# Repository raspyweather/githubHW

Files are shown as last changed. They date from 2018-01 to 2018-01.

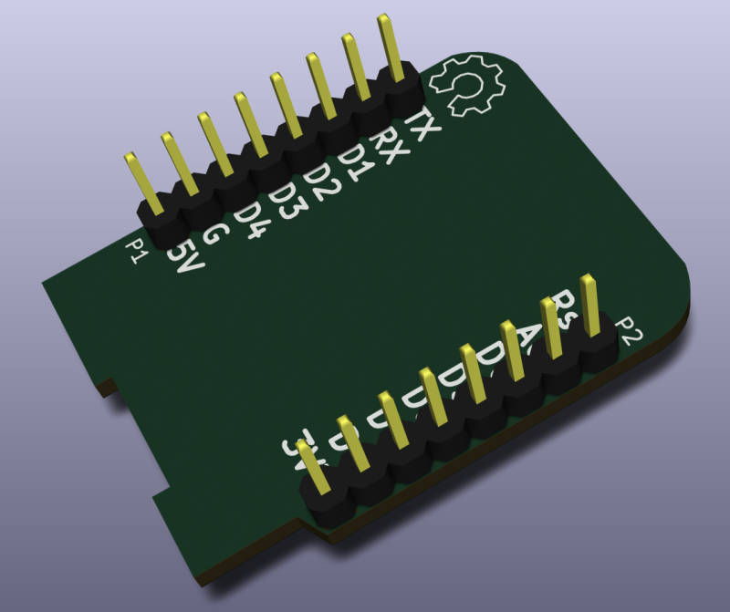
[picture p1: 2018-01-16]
d1_mini_kicad-master/template/meta/brd.png

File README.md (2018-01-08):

#  Github Calendar in Hardware
This is a very basic try to bring github's calendar to hardware. Who wouldn't like to get up and look at the glorious contribution history of the path?

just an image from githubs documentation

(not my calendar btw ☺)

# introduction
Since I'm a student, manufacturing cost need to be low, why I decided to use three 10cm x 10cm pcbs and solder all components by hand. Because it is cheaper using one mutli-purpose board than two specific pcb designs, I decided to do so, not assemblying unnecessary components on these boards. 

## first/main pcb
All parts assembled 
- WeMos D1 mini (KiCad files used from https://github.com/jerome-labidurie/d1_mini_kicad)
- 2x [TPIC6B595N](http://www.ti.com/lit/ds/symlink/tpic6b595.pdf)
- [TLC5940](http://www.ti.com/lit/ds/symlink/tlc5940.pdf)
- *some* leds
- 4x Buttons
- 1x Poti

pcb layout

## following two pcbs
- TLC5940
- *some* leds

## Total Circuit (connected ones)
only TLC5940 and leds assembled.
total scheme

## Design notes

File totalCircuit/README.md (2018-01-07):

# Total Circuit Scheme
This folder contains the schematic of all three pcbs needed for the total circuit.

It is only existing for documentary purposes.

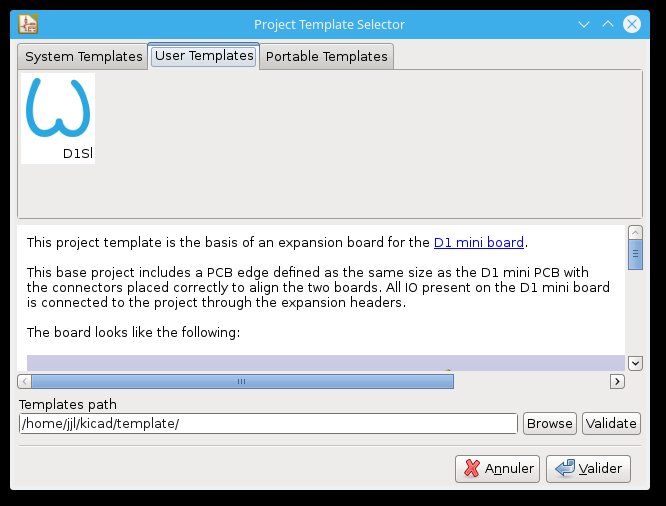
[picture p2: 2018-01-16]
d1_mini_kicad-master/work/img/screenshot1.jpg

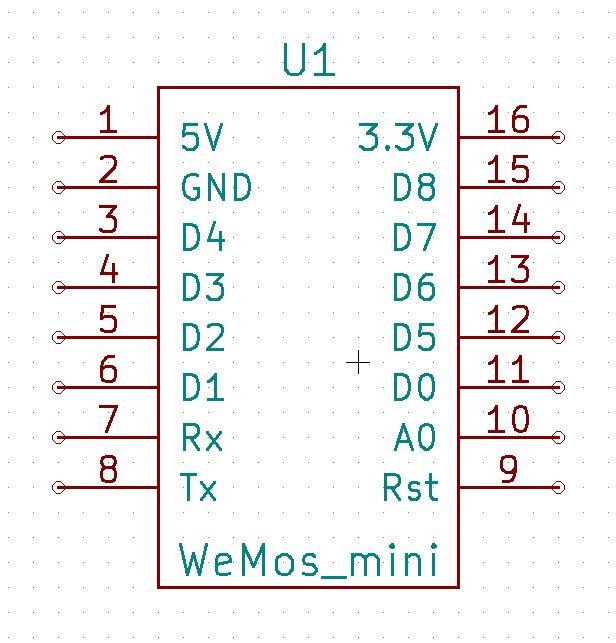
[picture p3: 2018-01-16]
d1_mini_kicad-master/work/img/screenshot2.jpg

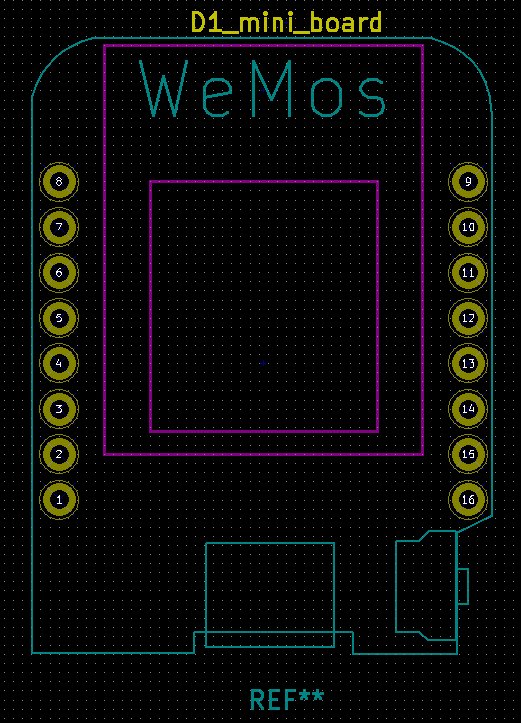
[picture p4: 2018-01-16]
d1_mini_kicad-master/work/img/screenshot3.jpg

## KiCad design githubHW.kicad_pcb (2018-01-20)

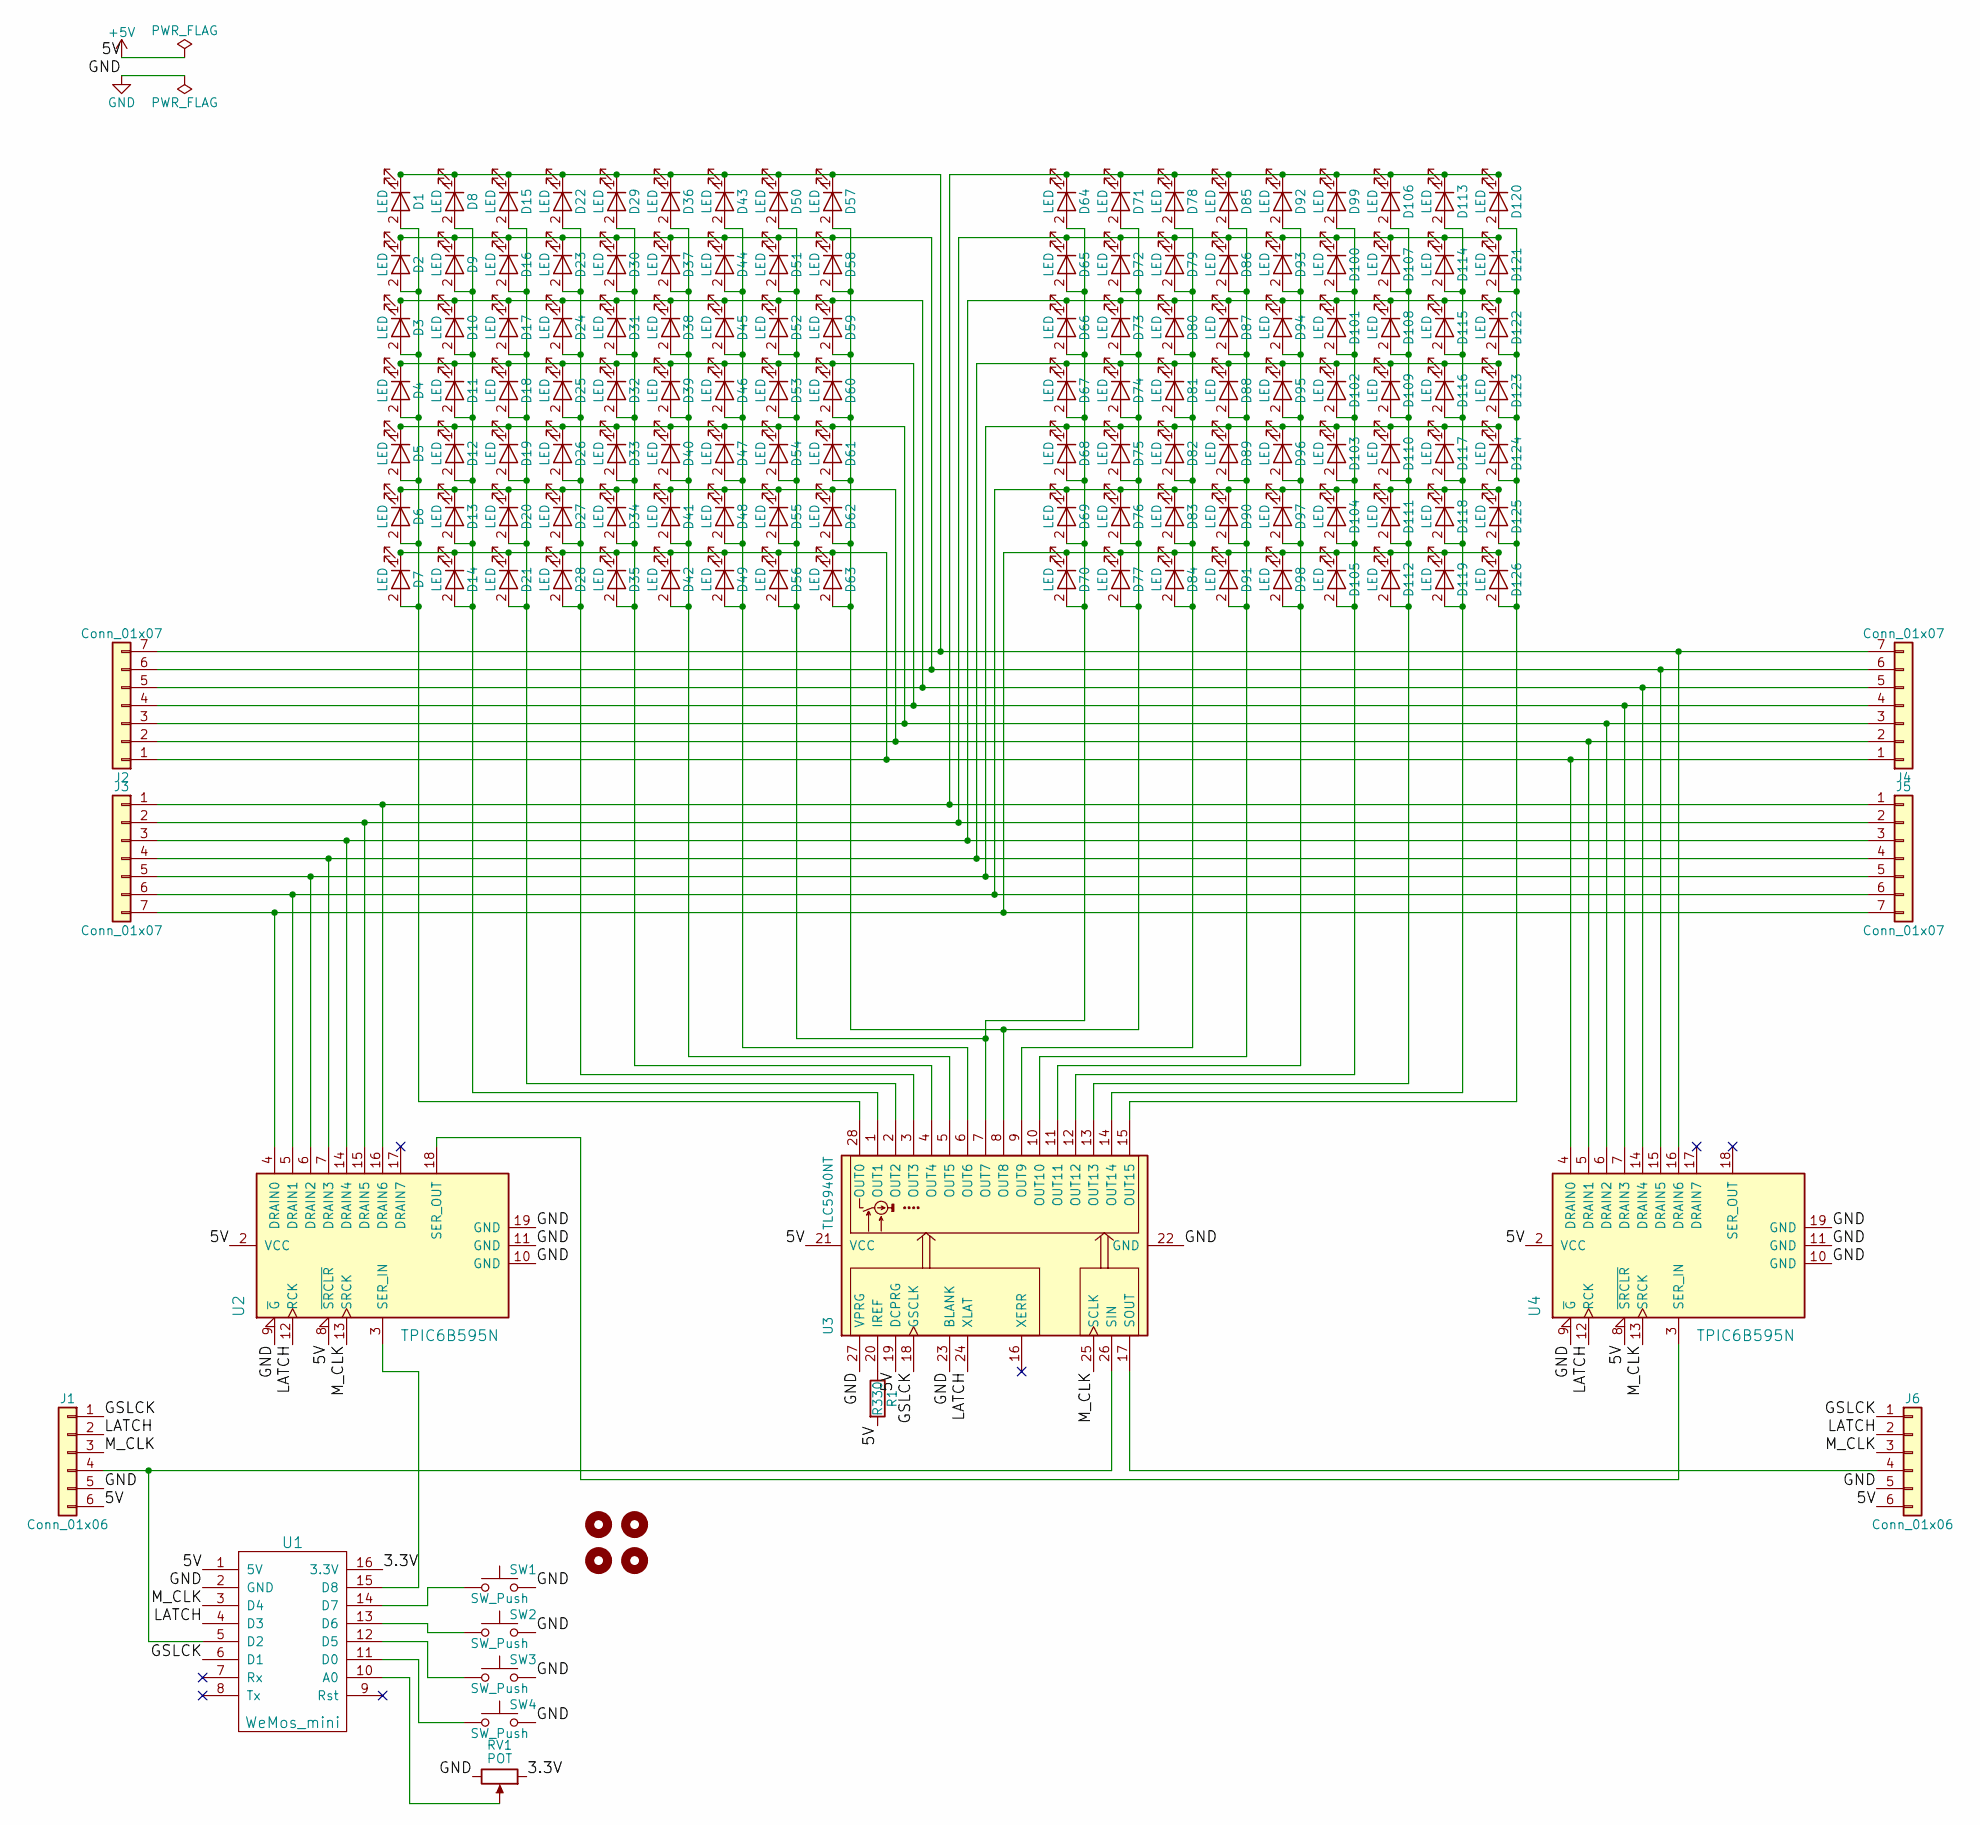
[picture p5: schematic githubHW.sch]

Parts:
D1, D2, D3, D4, D5, D6, D7, D8, D9, D10, D11, D12, D13, D14, D15, D16, D17, D18, D19, D20, D21, D22, D23, D24, D25, D26, D27, D28, D29, D30, D31, D32, D33, D34, D35, D36, D37, D38, D39, D40, D41, D42, D43, D44, D45, D46, D47, D48, D49, D50, D51, D52, D53, D54, D55, D56, D57, D58, D59, D60, D61, D62, D63, D64, D65, D66, D67, D68, D69, D70, D71, D72, D73, D74, D75, D76, D77, D78, D79, D80, D81, D82, D83, D84, D85, D86, D87, D88, D89, D90, D91, D92, D93, D94, D95, D96, D97, D98, D99, D100, D101, D102, D103, D104, D105, D106, D107, D108, D109, D110, D111, D112, D113, D114, D115, D116, D117, D118, D119, D120, D121, D122, D123, D124, D125, D126: LED; LED_D3.0mm
J1, J6: Conn_01x06; Pin_Header_Straight_1x06_Pitch2.00mm
J2, J3, J4, J5: Conn_01x07; Pin_Header_Straight_1x07_Pitch2.00mm
MH1, MH2, MH3, MH4: MOUNTHOLE; MountingHole_3.2mm_M3_ISO14580_Pad
R1: R330; R_Axial_DIN0204_L3.6mm_D1.6mm_P7.62mm_Horizontal
RV1: POT; Potentiometer_WirePads_largePads
SW1, SW2, SW3, SW4: SW_Push; SW_PUSH_6mm
U1: WeMos_mini; D1_mini_board
U2, U4: TPIC6B595N; DIP-20_W7.62mm
U3: TLC5940NT; DIP-28_W7.62mm

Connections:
+5V: J1.6, J6.6, R1.2, U1.1 (5V), U2.2 (VCC), U2.8 (~SRCLR), U3.19 (DCPRG), U3.21 (VCC), U4.2 (VCC), U4.8 (~SRCLR)
/3.3V: RV1.1, U1.16 (3.3V)
/GSLCK: J1.1, J6.1, U1.6 (D1), U3.18 (GSCLK)
/LATCH: J1.2, J6.2, U1.4 (D3), U2.12 (RCK), U3.24 (XLAT), U4.12 (RCK)
/M_CLK: J1.3, J6.3, U1.3 (D4), U2.13 (SRCK), U3.25 (SCLK), U4.13 (SRCK)
GND: J1.5, J6.5, RV1.3, SW1.2, SW2.2, SW3.2, SW4.2, U1.2 (GND), U2.9 (~G), U2.10 (GND), U2.11 (GND), U2.19 (GND), U3.22 (GND), U3.23 (BLANK), U3.27 (VPRG), U4.9 (~G), U4.10 (GND), U4.11 (GND), U4.19 (GND)
unnamed: D1.1 (K), D8.1 (K), D15.1 (K), D22.1 (K), D29.1 (K), D36.1 (K), D43.1 (K), D50.1 (K), D57.1 (K), J2.7, J4.7, U4.16 (DRAIN6)
unnamed: D1.2 (A), D2.2 (A), D3.2 (A), D4.2 (A), D5.2 (A), D6.2 (A), D7.2 (A), U3.28 (OUT0)
unnamed: D3.1 (K), D10.1 (K), D17.1 (K), D24.1 (K), D31.1 (K), D38.1 (K), D45.1 (K), D52.1 (K), D59.1 (K), J2.5, J4.5, U4.14 (DRAIN4)
unnamed: D8.2 (A), D9.2 (A), D10.2 (A), D11.2 (A), D12.2 (A), D13.2 (A), D14.2 (A), U3.1 (OUT1)
unnamed: D4.1 (K), D11.1 (K), D18.1 (K), D25.1 (K), D32.1 (K), D39.1 (K), D46.1 (K), D53.1 (K), D60.1 (K), J2.4, J4.4, U4.7 (DRAIN3)
unnamed: D5.1 (K), D12.1 (K), D19.1 (K), D26.1 (K), D33.1 (K), D40.1 (K), D47.1 (K), D54.1 (K), D61.1 (K), J2.3, J4.3, U4.6 (DRAIN2)
unnamed: D6.1 (K), D13.1 (K), D20.1 (K), D27.1 (K), D34.1 (K), D41.1 (K), D48.1 (K), D55.1 (K), D62.1 (K), J2.2, J4.2, U4.5 (DRAIN1)
unnamed: D7.1 (K), D14.1 (K), D21.1 (K), D28.1 (K), D35.1 (K), D42.1 (K), D49.1 (K), D56.1 (K), D63.1 (K), J2.1, J4.1, U4.4 (DRAIN0)
unnamed: D15.2 (A), D16.2 (A), D17.2 (A), D18.2 (A), D19.2 (A), D20.2 (A), D21.2 (A), U3.2 (OUT2)
unnamed: D2.1 (K), D9.1 (K), D16.1 (K), D23.1 (K), D30.1 (K), D37.1 (K), D44.1 (K), D51.1 (K), D58.1 (K), J2.6, J4.6, U4.15 (DRAIN5)
unnamed: D22.2 (A), D23.2 (A), D24.2 (A), D25.2 (A), D26.2 (A), D27.2 (A), D28.2 (A), U3.3 (OUT3)
unnamed: D29.2 (A), D30.2 (A), D31.2 (A), D32.2 (A), D33.2 (A), D34.2 (A), D35.2 (A), U3.4 (OUT4)
unnamed: D36.2 (A), D37.2 (A), D38.2 (A), D39.2 (A), D40.2 (A), D41.2 (A), D42.2 (A), U3.5 (OUT5)
unnamed: D43.2 (A), D44.2 (A), D45.2 (A), D46.2 (A), D47.2 (A), D48.2 (A), D49.2 (A), U3.6 (OUT6)
unnamed: D50.2 (A), D51.2 (A), D52.2 (A), D53.2 (A), D54.2 (A), D55.2 (A), D56.2 (A), D64.2 (A), D65.2 (A), D66.2 (A), D67.2 (A), D68.2 (A), D69.2 (A), D70.2 (A), U3.7 (OUT7)
unnamed: D57.2 (A), D58.2 (A), D59.2 (A), D60.2 (A), D61.2 (A), D62.2 (A), D63.2 (A), D71.2 (A), D72.2 (A), D73.2 (A), D74.2 (A), D75.2 (A), D76.2 (A), D77.2 (A), U3.8 (OUT8)
unnamed: D78.2 (A), D79.2 (A), D80.2 (A), D81.2 (A), D82.2 (A), D83.2 (A), D84.2 (A), U3.9 (OUT9)
unnamed: D85.2 (A), D86.2 (A), D87.2 (A), D88.2 (A), D89.2 (A), D90.2 (A), D91.2 (A), U3.10 (OUT10)
unnamed: D92.2 (A), D93.2 (A), D94.2 (A), D95.2 (A), D96.2 (A), D97.2 (A), D98.2 (A), U3.11 (OUT11)
unnamed: D65.1 (K), D72.1 (K), D79.1 (K), D86.1 (K), D93.1 (K), D100.1 (K), D107.1 (K), D114.1 (K), D121.1 (K), J3.2, J5.2, U2.15 (DRAIN5)
unnamed: D99.2 (A), D100.2 (A), D101.2 (A), D102.2 (A), D103.2 (A), D104.2 (A), D105.2 (A), U3.12 (OUT12)
unnamed: D66.1 (K), D73.1 (K), D80.1 (K), D87.1 (K), D94.1 (K), D101.1 (K), D108.1 (K), D115.1 (K), D122.1 (K), J3.3, J5.3, U2.14 (DRAIN4)
unnamed: D67.1 (K), D74.1 (K), D81.1 (K), D88.1 (K), D95.1 (K), D102.1 (K), D109.1 (K), D116.1 (K), D123.1 (K), J3.4, J5.4, U2.7 (DRAIN3)
unnamed: D68.1 (K), D75.1 (K), D82.1 (K), D89.1 (K), D96.1 (K), D103.1 (K), D110.1 (K), D117.1 (K), D124.1 (K), J3.5, J5.5, U2.6 (DRAIN2)
unnamed: D69.1 (K), D76.1 (K), D83.1 (K), D90.1 (K), D97.1 (K), D104.1 (K), D111.1 (K), D118.1 (K), D125.1 (K), J3.6, J5.6, U2.5 (DRAIN1)
unnamed: D70.1 (K), D77.1 (K), D84.1 (K), D91.1 (K), D98.1 (K), D105.1 (K), D112.1 (K), D119.1 (K), D126.1 (K), J3.7, J5.7, U2.4 (DRAIN0)
unnamed: D64.1 (K), D71.1 (K), D78.1 (K), D85.1 (K), D92.1 (K), D99.1 (K), D106.1 (K), D113.1 (K), D120.1 (K), J3.1, J5.1, U2.16 (DRAIN6)
unnamed: D106.2 (A), D107.2 (A), D108.2 (A), D109.2 (A), D110.2 (A), D111.2 (A), D112.2 (A), U3.13 (OUT13)
unnamed: D113.2 (A), D114.2 (A), D115.2 (A), D116.2 (A), D117.2 (A), D118.2 (A), D119.2 (A), U3.14 (OUT14)
unnamed: D120.2 (A), D121.2 (A), D122.2 (A), D123.2 (A), D124.2 (A), D125.2 (A), D126.2 (A), U3.15 (OUT15)
unnamed: J1.4, U1.5 (D2), U3.26 (SIN)
unnamed: J6.4, U3.17 (SOUT)
unnamed: R1.1, U3.20 (IREF)
unnamed: RV1.2, U1.10 (A0)
unnamed: SW1.1, U1.14 (D7)
unnamed: SW2.1, U1.13 (D6)
unnamed: SW3.1, U1.12 (D5)
unnamed: SW4.1, U1.11 (D0)
unnamed: U1.15 (D8), U2.3 (SER_IN)
unnamed: U2.18 (SER_OUT), U4.3 (SER_IN)

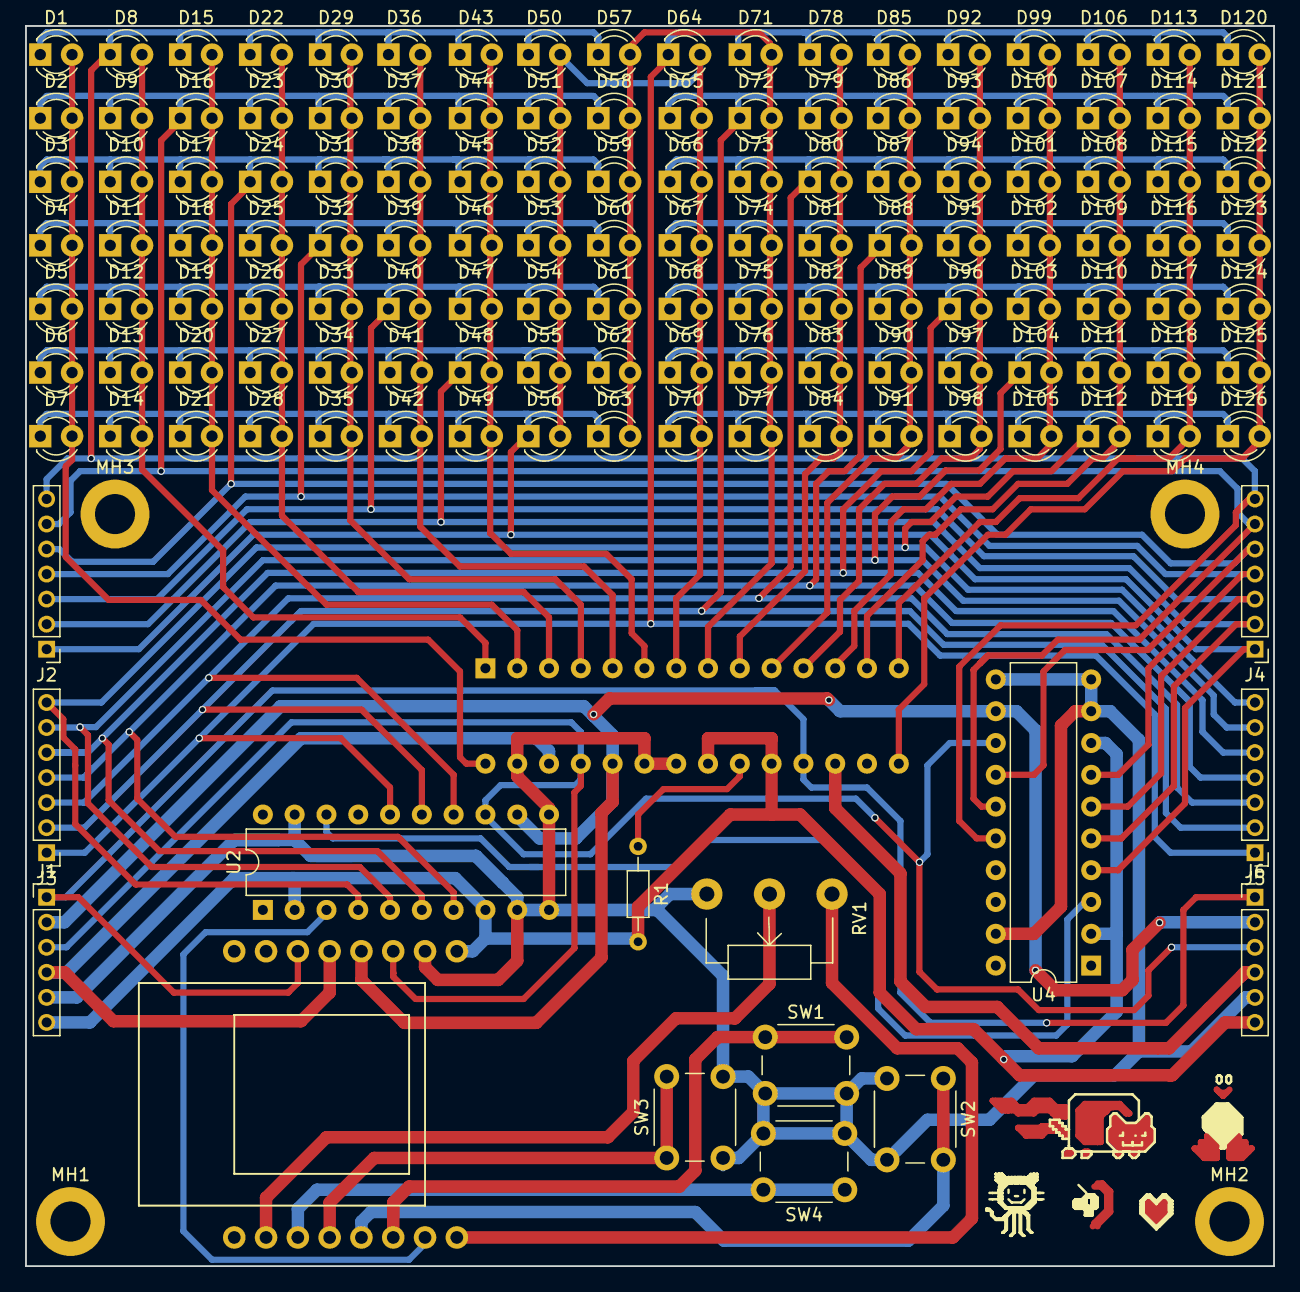
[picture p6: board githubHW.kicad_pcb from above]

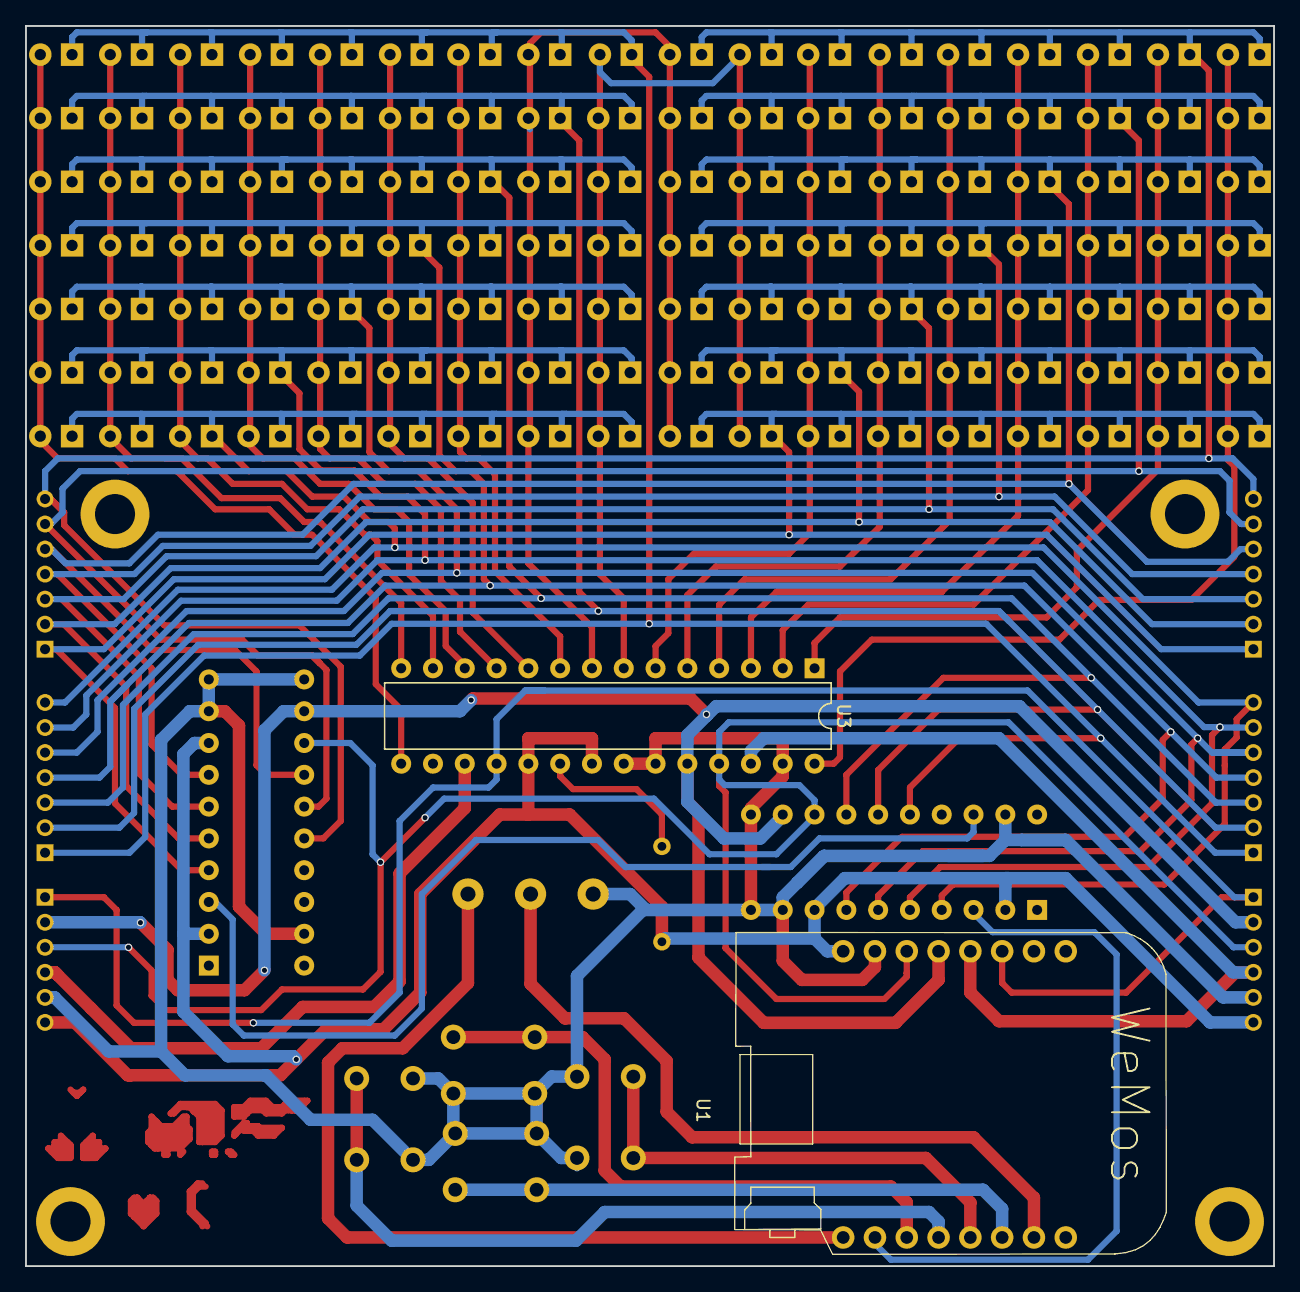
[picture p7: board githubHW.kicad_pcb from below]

Board: 2 copper layers, 99.7 x 99.1 mm, 146 parts (2 on the bottom side), 46 nets.

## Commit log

2017-12-30 files added to vcs
    [githubHW.kicad_pcb, githubHW.sch]
2017-12-30 plotted pcb view added
2018-01-01 connection issue fixed
    [githubHW.kicad_pcb, githubHW.sch]
2018-01-01 board svg updated
2018-01-01 buttons connection changed
    now using WeMos' pullups
    [githubHW.kicad_pcb, githubHW.sch]
2018-01-07 Revert "connection issue fixed"
    This reverts commit d7eb6beb1c8d570a5e8c06e88c024579e6cb722b.
    [githubHW.kicad_pcb, githubHW.sch]
2018-01-07 submodule removed and readded as folder
    [githubHW.sch]
2018-01-07 documentation updated
    [githubHW.sch]
2018-01-09 poti connection corrected
    [githubHW.kicad_pcb, githubHW.sch]
2018-01-16 wemos files commited for better usability.
    [d1_mini_shield.kicad_pcb, d1_mini_shield.sch, githubHW.kicad_pcb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]
2018-01-17 scheme simplified for easier control
    [_saved_githubHW.sch, githubHW.kicad_pcb]
2018-01-18 tux added ♥
    [githubHW.kicad_pcb, githubHW.sch]
2018-01-20 removed backup file
    [_saved_githubHW.sch]
2018-01-20 gerber files added
    [githubHW-B.Cu.gbr, githubHW-B.Mask.gbr, githubHW-B.SilkS.gbr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]
